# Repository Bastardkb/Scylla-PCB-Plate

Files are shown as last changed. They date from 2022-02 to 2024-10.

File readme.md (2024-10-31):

# Scylla PCB - plate

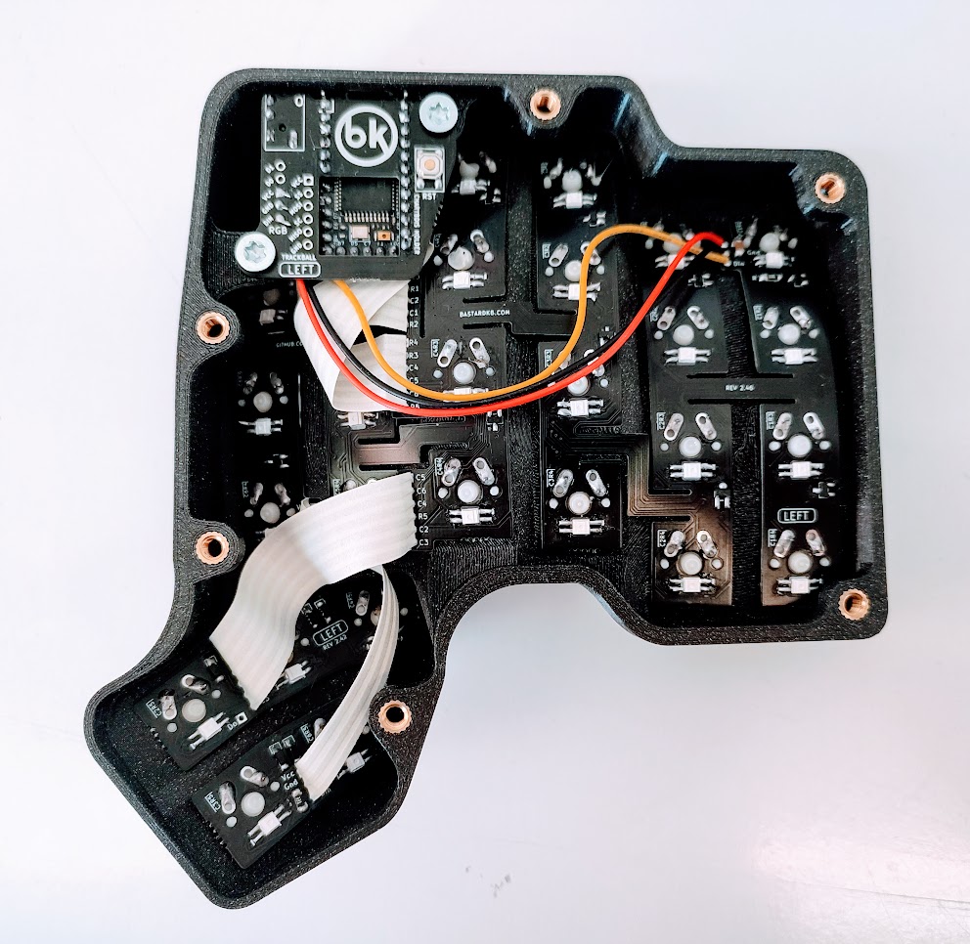
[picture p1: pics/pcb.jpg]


Flexible PCB made for the Scylla.

With per-key RGB.

This repository contains all files necessary to order a PCB.

If you want to modify the design files, the Kicad sources are included.
<!-- If you just want to order the PCBs, check out the Release section which contain the gerber files. -->

## How to order

Order with a 0.6mm or 0.8mm PCB thickness

## License

Licensed under CC BY-NC-SA 4.0
Copyright Quentin Lebastard 2021

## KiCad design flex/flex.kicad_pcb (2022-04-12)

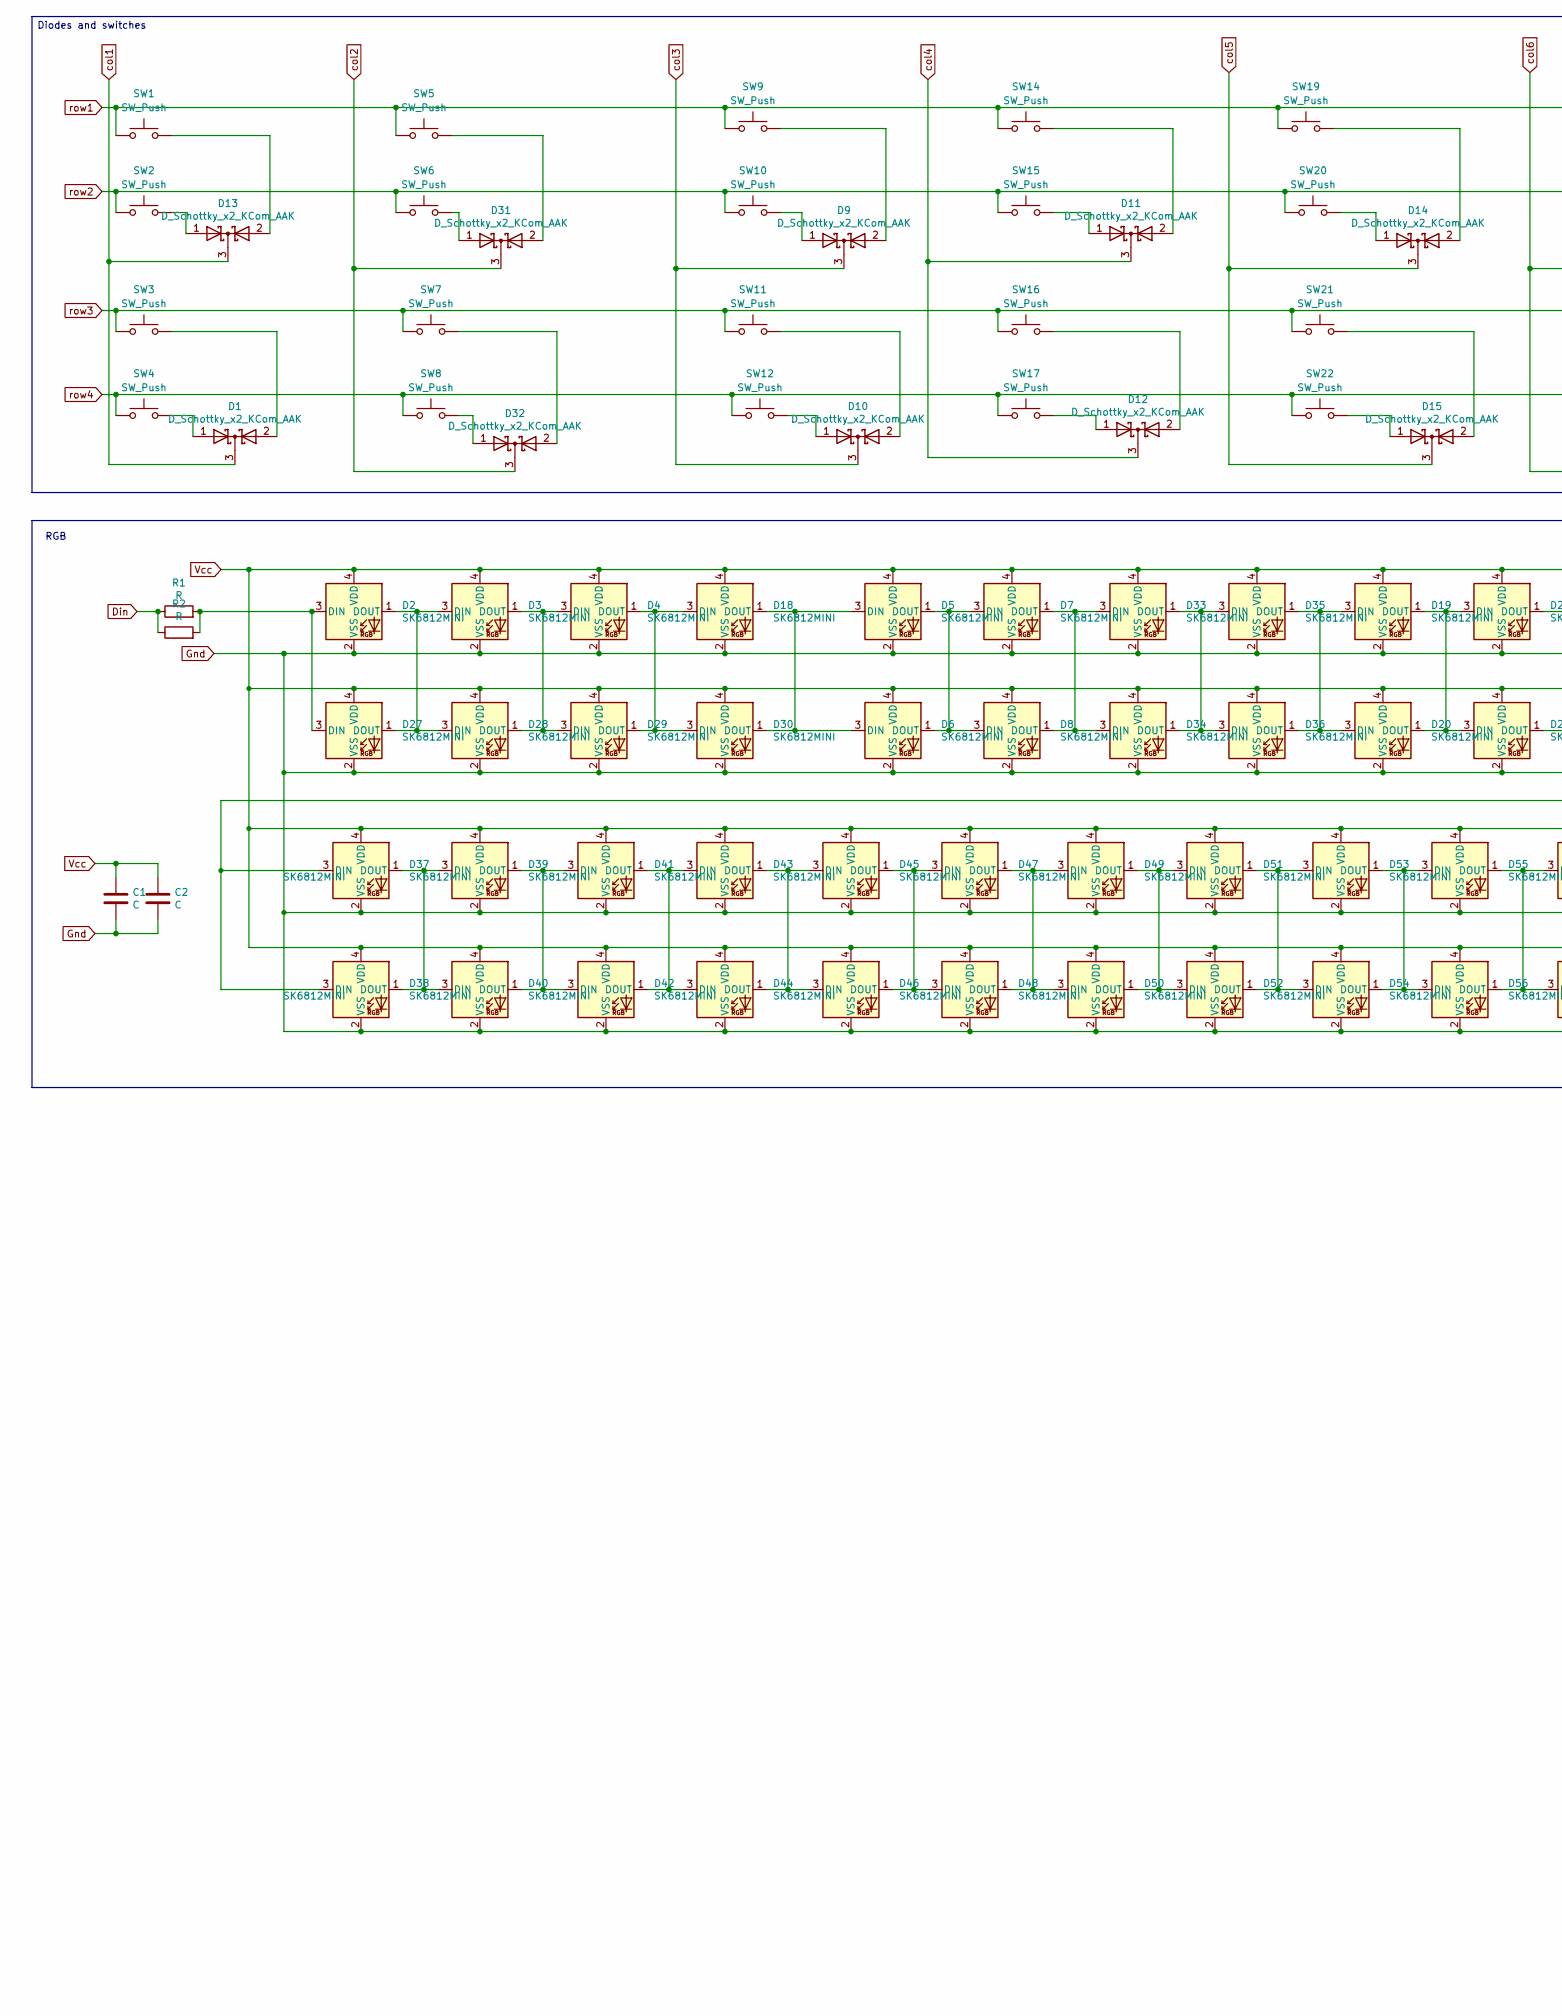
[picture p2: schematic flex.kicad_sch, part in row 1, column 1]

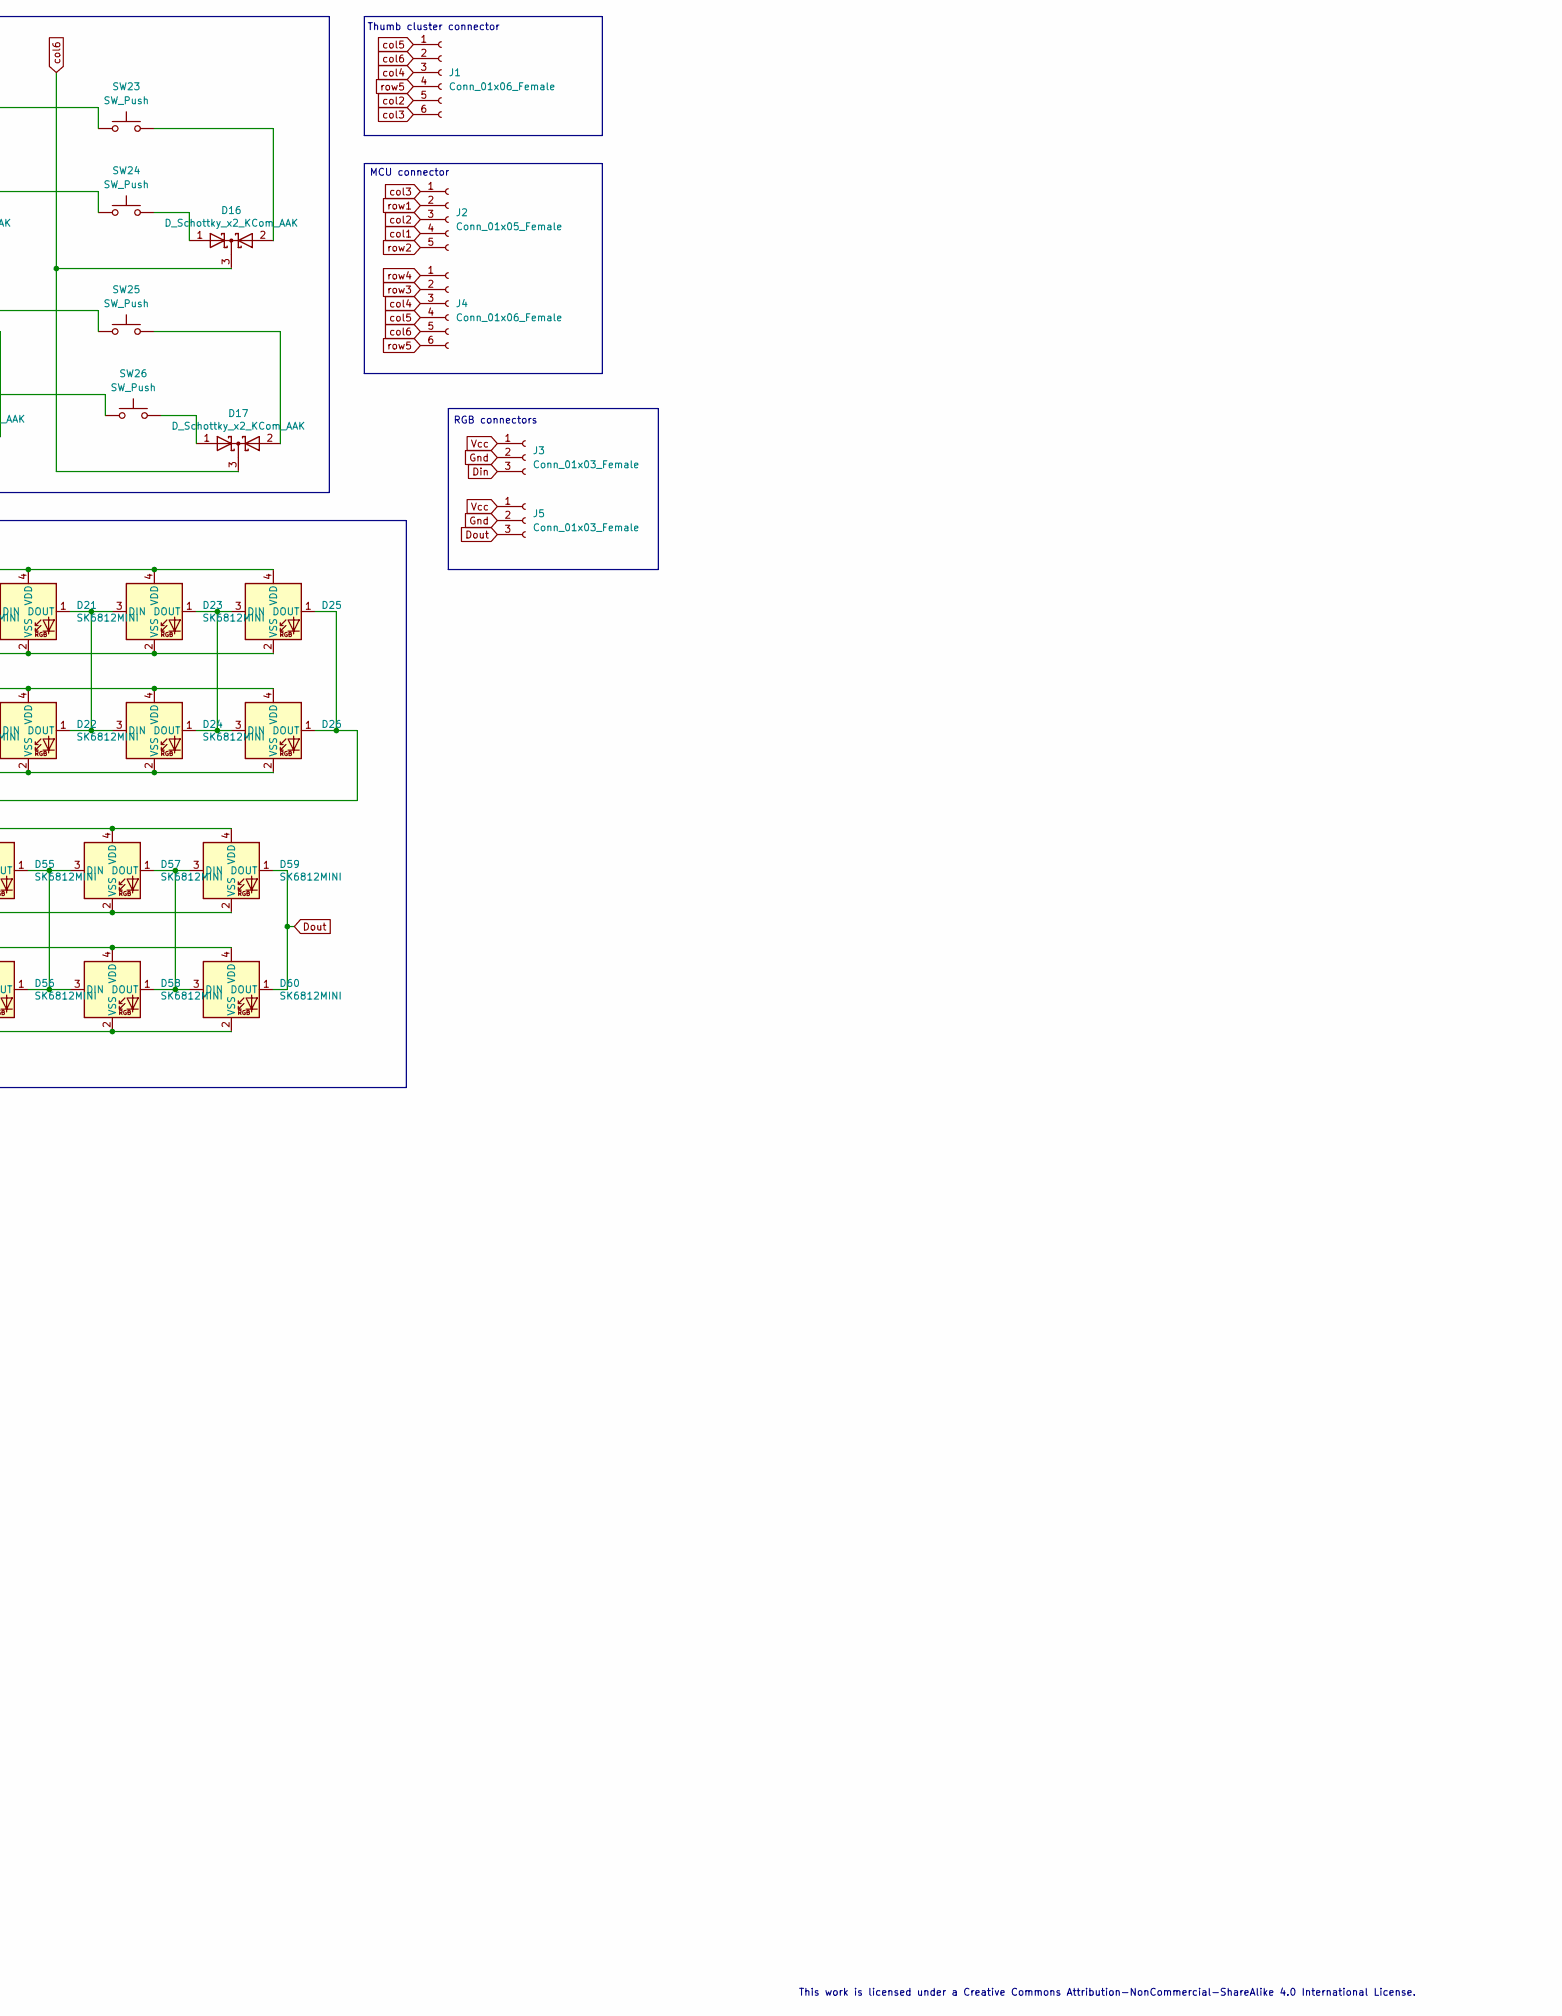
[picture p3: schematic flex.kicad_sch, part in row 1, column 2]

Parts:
C1, C2: C; C_1206_3216Metric_Pad1.42x1.75mm_HandSolder
D1, D9, D10, D11, D12, D13, D14, D15, D16, D17, D31, D32: D_Schottky_x2_KCom_AAK; TSOT-23_HandSoldering
D2, D3, D4, D5, D7, D18, D19, D21, D23, D25, D33, D35, D37, D39, D41, D43, D45, D47, D49, D51, D53, D55, D57, D59: SK6812MINI; YS-SK6812MINI-E_REVERSE
D6, D8, D20, D22, D24, D26, D27, D28, D29, D30, D34, D36, D38, D40, D42, D44, D46, D48, D50, D52, D54, D56, D58, D60: SK6812MINI; YS-SK6812MINI-E_REVERSE_NO_EDGECUT
J1, J4: Conn_01x06_Female; PinHeader_1x06_P2.54mm_Vertical
J2: Conn_01x05_Female; PinHeader_1x05_P2.54mm_Vertical
J3, J5: Conn_01x03_Female; PinHeader_1x03_P2.54mm_Vertical
R1, R2: R; R_1206_3216Metric_Pad1.42x1.75mm_HandSolder
SW1, SW2, SW3, SW4, SW5, SW6, SW7, SW8, SW9, SW10, SW11, SW12, SW14, SW15, SW16, SW17, SW19, SW20, SW21, SW22, SW23, SW24, SW25, SW26: SW_Push; SW_MX_reversible

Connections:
Din: J3.3, R1.1, R2.1
Dout: D59.1 (DOUT), D60.1 (DOUT), J5.3
Gnd: C1.2, C2.2, D2.2 (VSS), D3.2 (VSS), D4.2 (VSS), D5.2 (VSS), D6.2 (VSS), D7.2 (VSS), D8.2 (VSS), D18.2 (VSS), D19.2 (VSS), D20.2 (VSS), D21.2 (VSS), D22.2 (VSS), D23.2 (VSS), D24.2 (VSS), D25.2 (VSS), D26.2 (VSS), D27.2 (VSS), D28.2 (VSS), D29.2 (VSS), D30.2 (VSS), D33.2 (VSS), D34.2 (VSS), D35.2 (VSS), D36.2 (VSS), D37.2 (VSS), D38.2 (VSS), D39.2 (VSS), D40.2 (VSS), D41.2 (VSS), D42.2 (VSS), D43.2 (VSS), D44.2 (VSS), D45.2 (VSS), D46.2 (VSS), D47.2 (VSS), D48.2 (VSS), D49.2 (VSS), D50.2 (VSS), D51.2 (VSS), D52.2 (VSS), D53.2 (VSS), D54.2 (VSS), D55.2 (VSS), D56.2 (VSS), D57.2 (VSS), D58.2 (VSS), D59.2 (VSS), D60.2 (VSS), J3.2, J5.2
unnamed: D1.1 (A), SW4.2
unnamed: D1.2 (A), SW3.2
unnamed: D2.1 (DOUT), D3.3 (DIN), D27.1 (DOUT), D28.3 (DIN)
unnamed: D2.3 (DIN), D27.3 (DIN), R1.2, R2.2
unnamed: D5.1 (DOUT), D6.1 (DOUT), D7.3 (DIN), D8.3 (DIN)
unnamed: D9.1 (A), SW10.2
unnamed: D9.2 (A), SW9.2
unnamed: D10.1 (A), SW12.2
unnamed: D10.2 (A), SW11.2
unnamed: D11.1 (A), SW15.2
unnamed: D11.2 (A), SW14.2
unnamed: D12.1 (A), SW17.2
unnamed: D12.2 (A), SW16.2
unnamed: D13.1 (A), SW2.2
unnamed: D13.2 (A), SW1.2
unnamed: D14.1 (A), SW20.2
unnamed: D14.2 (A), SW19.2
unnamed: D15.1 (A), SW22.2
unnamed: D15.2 (A), SW21.2
unnamed: D16.1 (A), SW24.2
unnamed: D16.2 (A), SW23.2
unnamed: D17.1 (A), SW26.2
unnamed: D17.2 (A), SW25.2
unnamed: D5.3 (DIN), D6.3 (DIN), D18.1 (DOUT), D30.1 (DOUT)
unnamed: D4.1 (DOUT), D18.3 (DIN), D29.1 (DOUT), D30.3 (DIN)
unnamed: D19.1 (DOUT), D20.1 (DOUT), D21.3 (DIN), D22.3 (DIN)
unnamed: D19.3 (DIN), D20.3 (DIN), D35.1 (DOUT), D36.1 (DOUT)
unnamed: D21.1 (DOUT), D22.1 (DOUT), D23.3 (DIN), D24.3 (DIN)
unnamed: D23.1 (DOUT), D24.1 (DOUT), D25.3 (DIN), D26.3 (DIN)
unnamed: D25.1 (DOUT), D26.1 (DOUT), D37.3 (DIN), D38.3 (DIN)
unnamed: D3.1 (DOUT), D4.3 (DIN), D28.1 (DOUT), D29.3 (DIN)
unnamed: D31.1 (A), SW6.2
unnamed: D31.2 (A), SW5.2
unnamed: D32.1 (A), SW8.2
unnamed: D32.2 (A), SW7.2
unnamed: D33.1 (DOUT), D34.1 (DOUT), D35.3 (DIN), D36.3 (DIN)
unnamed: D7.1 (DOUT), D8.1 (DOUT), D33.3 (DIN), D34.3 (DIN)
unnamed: D37.1 (DOUT), D38.1 (DOUT), D39.3 (DIN), D40.3 (DIN)
unnamed: D39.1 (DOUT), D40.1 (DOUT), D41.3 (DIN), D42.3 (DIN)
unnamed: D41.1 (DOUT), D42.1 (DOUT), D43.3 (DIN), D44.3 (DIN)
unnamed: D43.1 (DOUT), D44.1 (DOUT), D45.3 (DIN), D46.3 (DIN)
unnamed: D45.1 (DOUT), D46.1 (DOUT), D47.3 (DIN), D48.3 (DIN)
unnamed: D47.1 (DOUT), D48.1 (DOUT), D49.3 (DIN), D50.3 (DIN)
unnamed: D49.1 (DOUT), D50.1 (DOUT), D51.3 (DIN), D52.3 (DIN)
unnamed: D51.1 (DOUT), D52.1 (DOUT), D53.3 (DIN), D54.3 (DIN)
unnamed: D53.1 (DOUT), D54.1 (DOUT), D55.3 (DIN), D56.3 (DIN)
unnamed: D55.1 (DOUT), D56.1 (DOUT), D57.3 (DIN), D58.3 (DIN)
unnamed: D57.1 (DOUT), D58.1 (DOUT), D59.3 (DIN), D60.3 (DIN)
Vcc: C1.1, C2.1, D2.4 (VDD), D3.4 (VDD), D4.4 (VDD), D5.4 (VDD), D6.4 (VDD), D7.4 (VDD), D8.4 (VDD), D18.4 (VDD), D19.4 (VDD), D20.4 (VDD), D21.4 (VDD), D22.4 (VDD), D23.4 (VDD), D24.4 (VDD), D25.4 (VDD), D26.4 (VDD), D27.4 (VDD), D28.4 (VDD), D29.4 (VDD), D30.4 (VDD), D33.4 (VDD), D34.4 (VDD), D35.4 (VDD), D36.4 (VDD), D37.4 (VDD), D38.4 (VDD), D39.4 (VDD), D40.4 (VDD), D41.4 (VDD), D42.4 (VDD), D43.4 (VDD), D44.4 (VDD), D45.4 (VDD), D46.4 (VDD), D47.4 (VDD), D48.4 (VDD), D49.4 (VDD), D50.4 (VDD), D51.4 (VDD), D52.4 (VDD), D53.4 (VDD), D54.4 (VDD), D55.4 (VDD), D56.4 (VDD), D57.4 (VDD), D58.4 (VDD), D59.4 (VDD), D60.4 (VDD), J3.1, J5.1
col1: D1.3 (K), D13.3 (K), J2.4
col2: D31.3 (K), D32.3 (K), J1.5, J2.3
col3: D9.3 (K), D10.3 (K), J1.6, J2.1
col4: D11.3 (K), D12.3 (K), J1.3, J4.3
col5: D14.3 (K), D15.3 (K), J1.1, J4.4
col6: D16.3 (K), D17.3 (K), J1.2, J4.5
row1: J2.2, SW1.1, SW5.1, SW9.1, SW14.1, SW19.1, SW23.1
row2: J2.5, SW2.1, SW6.1, SW10.1, SW15.1, SW20.1, SW24.1
row3: J4.2, SW3.1, SW7.1, SW11.1, SW16.1, SW21.1, SW25.1
row4: J4.1, SW4.1, SW8.1, SW12.1, SW17.1, SW22.1, SW26.1
row5: J1.4, J4.6

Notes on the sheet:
Diodes and switches
RGB
MCU connector
Thumb cluster connector
This work is licensed under a Creative Commons Attribution-NonCommercial-ShareAlike 4.0 International License.
RGB connectors

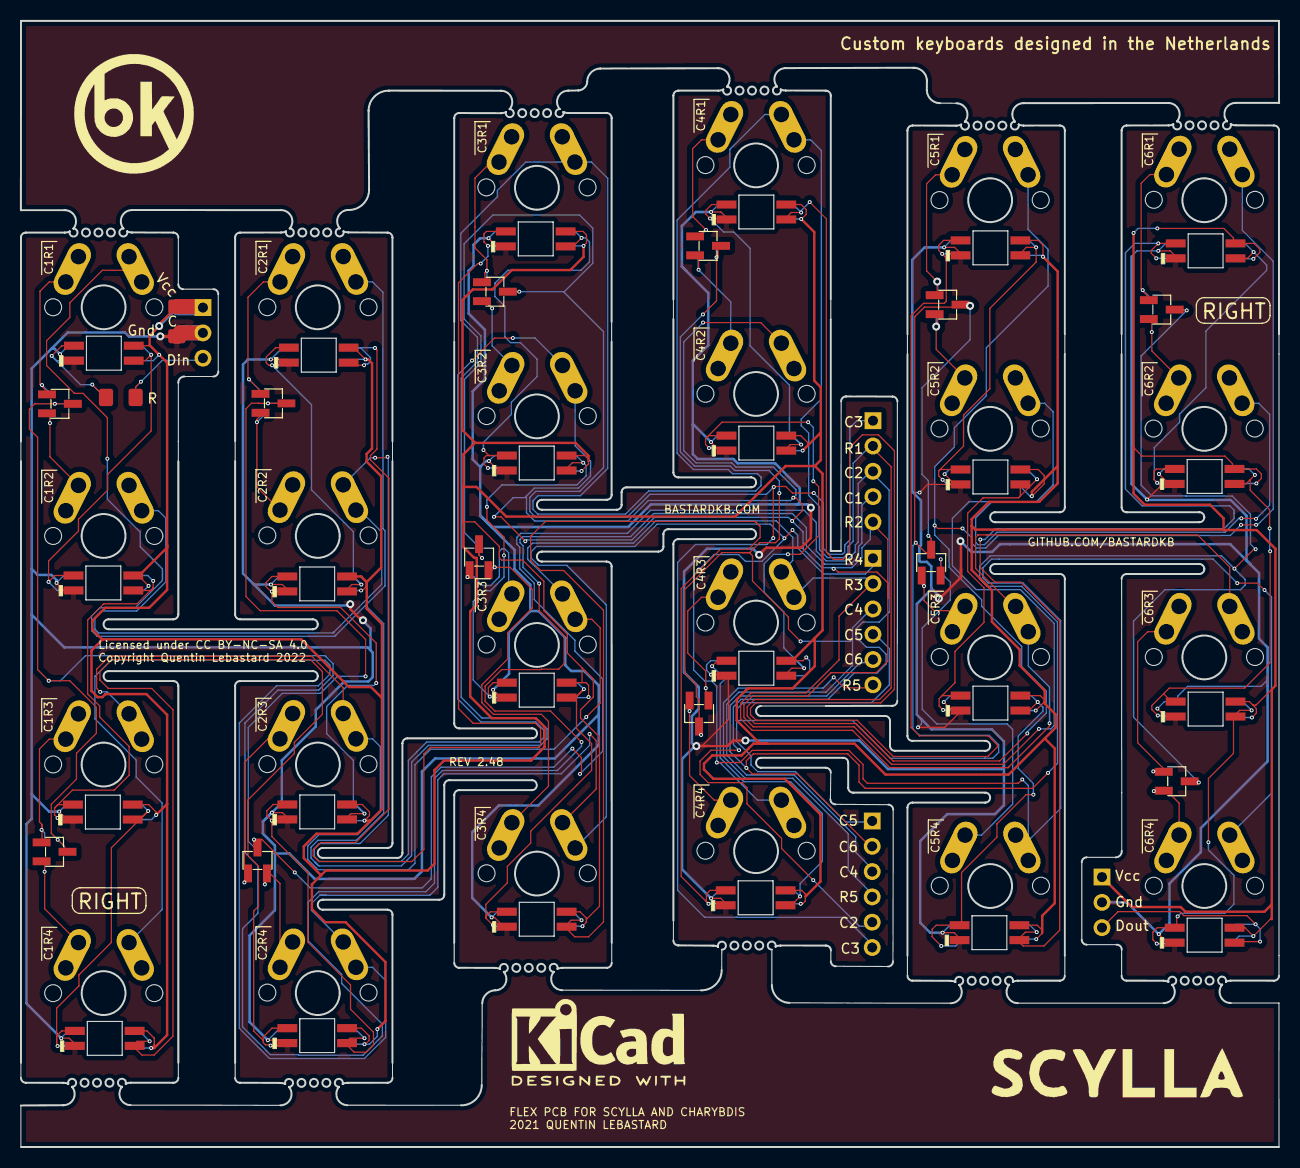
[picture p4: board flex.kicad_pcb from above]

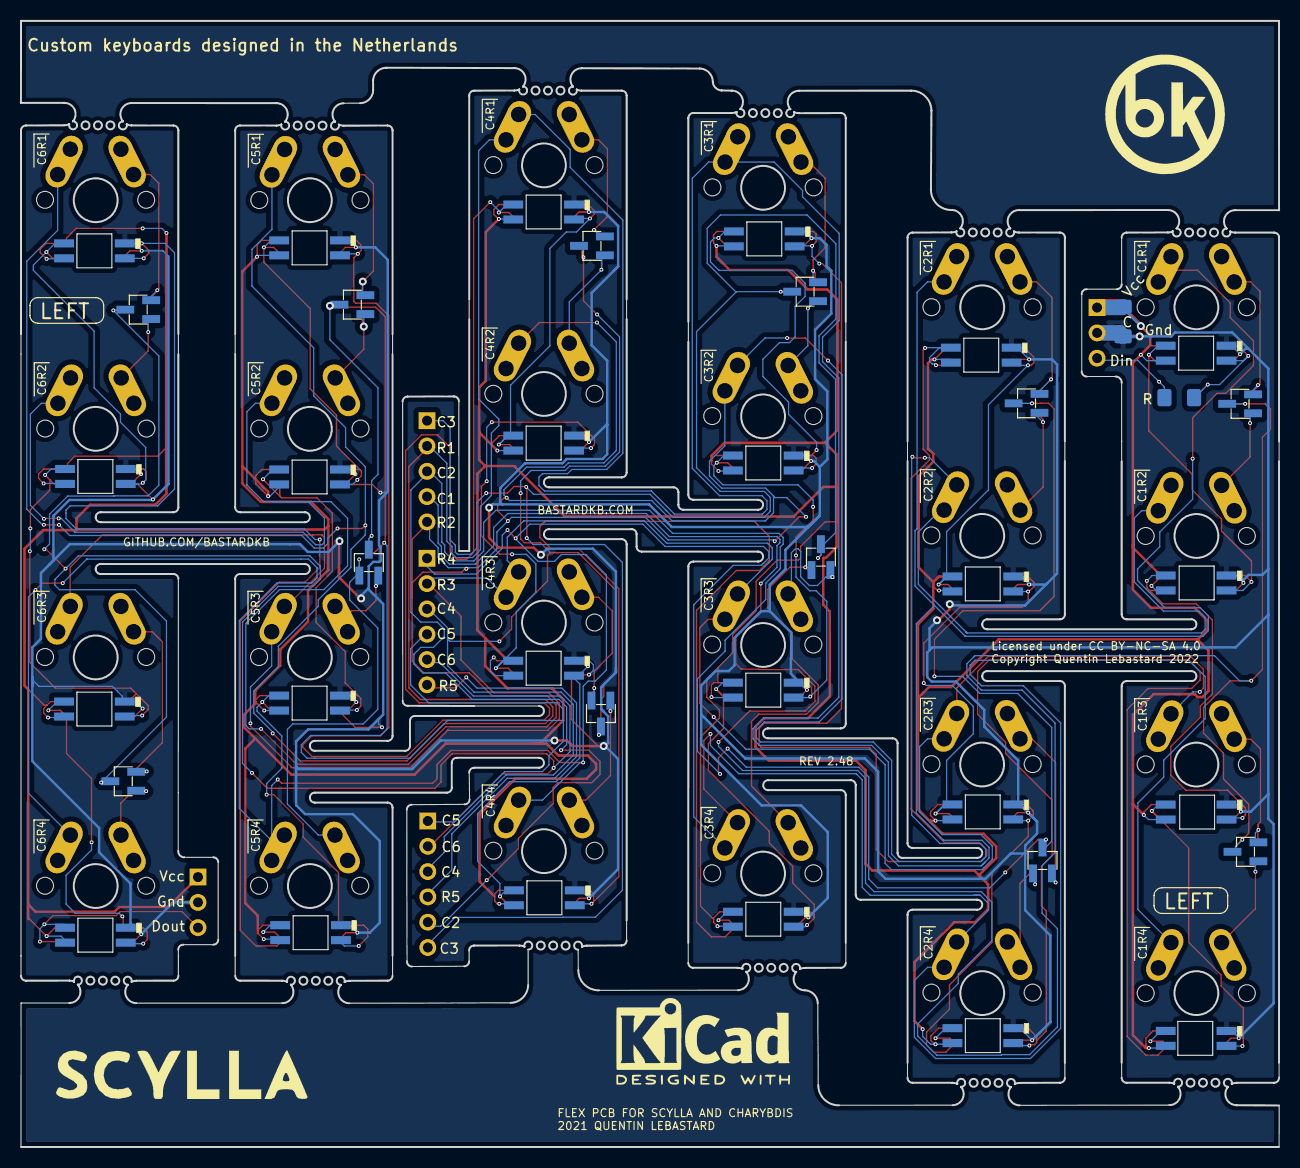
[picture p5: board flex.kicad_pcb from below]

Board: 2 copper layers, 126.3 x 113.0 mm, 93 parts (50 on the bottom side), 63 nets.

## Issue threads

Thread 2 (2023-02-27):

TODO assembled version

bstiq, 2023-02-27:
- [ ] same rgb footprint as dilemma, just longer pads
- [ ] use 0402 or 0201 diodes, in clusters - eg. sod523 (C122862)
- [ ] new edge cuts

Closed 2023-03-09.

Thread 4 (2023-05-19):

common problems

bstiq, 2023-05-19:
- D key diode failing
- row connection between W and E failing
- R2 connection between row and plate connector failing
- shorts C1/R2

Closed 2025-01-16.

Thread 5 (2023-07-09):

Left PCB?

gorbachev, 2023-07-09:
The project only includes the right-side PCB. Build guide has images of a left-side PCB with different silkscreen (e.g. "Left" printed on the PCB).

What's the process for fabricating a left-side PCB? Is it merely reversible? Or are there other changes required?

bstiq, 2023-07-11:
Hi,

All the PCBs are reversible yes, just order as is.
You can also open them in kicad to check yourself, the other side shows "left" just like you mentioned.

Regards,

Closed 2023-07-11.

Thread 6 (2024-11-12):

upgrades

bstiq, 2024-11-12:
- [ ] solidify ribbon cable connection
- [ ] switch to 1206 diodes
- [ ] ?horizontal diodes?
- [ ] double diode footprint (for assembly)
- [ ] new rgb led footprints (with GND + pin 1 marking)
- [ ] north facing RGB

KorribanMaster, 2025-08-30:
Hey i just assembled my charybdis keyboard and first of all great work. however when assembling i had quite a fight with the stiff connector cables and didnt really like how muw strain this puts on the pcb. I just made a try to replace the connectors with fpc 14 pin 0.5 mm pitch and after a short try this might just fit. i chose 14 pin in order to  add only one item to the bom. otherwise a 1.27 inch pitch micromatch connector might also be a good fit these are easier for handsoldering and the cable side can be easily crimped to a generic ribbon cable using pliers and most of the routing could remain unchanged as they are available as through hole

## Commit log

2022-02-20 add stuff
    [flex.kicad_pcb, flex.kicad_sch]
2022-02-20 edge cuts, via size
    [flex.kicad_pcb]
2022-02-22 revert routing
    [flex.kicad_pcb]
2022-04-12 cleanup and reinforce c4/c5 connection
    [flex.kicad_pcb]

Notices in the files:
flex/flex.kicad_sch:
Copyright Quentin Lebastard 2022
